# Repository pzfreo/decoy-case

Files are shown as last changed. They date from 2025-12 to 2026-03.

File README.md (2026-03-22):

# decoy-case




A small 3D printed enclosure for a [common USB-C decoy board](https://www.amazon.co.uk/dp/B0FNQNY8PT), built with [build123d](https://github.com/gumyr/build123d).

You can customise how tall the entry is for the wire at the back.

## How it works

1. `decoy_case.py` generates two STEP files (base + shell) using build123d
2. CI builds the STEP files on every push/PR
3. [fabprint](https://github.com/pzfreo/fabprint) slices them with OrcaSlicer in CI, producing print-ready gcode
4. PRs get a comment with estimated print time and filament usage

## Usage

```bash
pip install build123d
python decoy_case.py
```

This generates `decoy_base.step` and `decoy_shell.step`.

To slice locally:

```bash
pip install fabprint
fabprint run
```

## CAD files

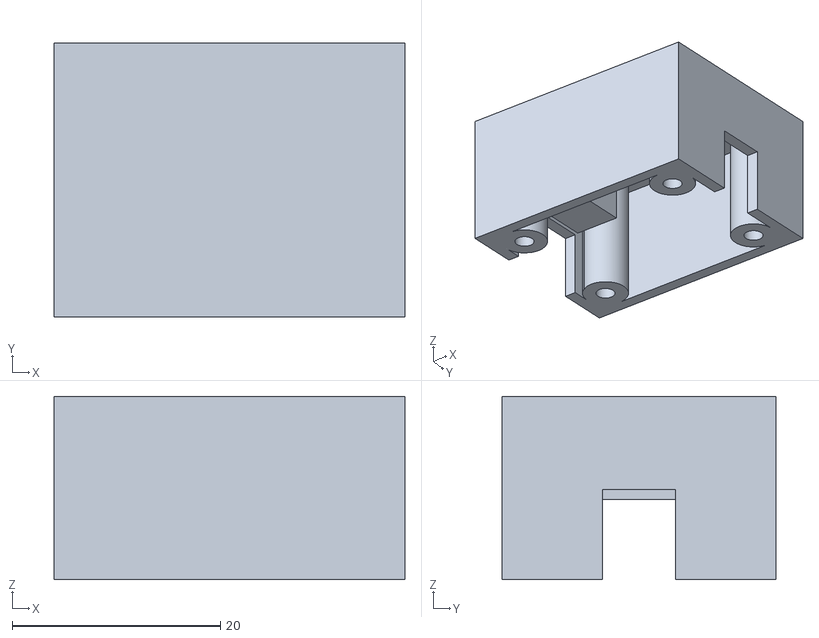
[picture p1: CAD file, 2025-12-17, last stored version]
decoy_shell.stl
33.7 x 26.4 x 17.6

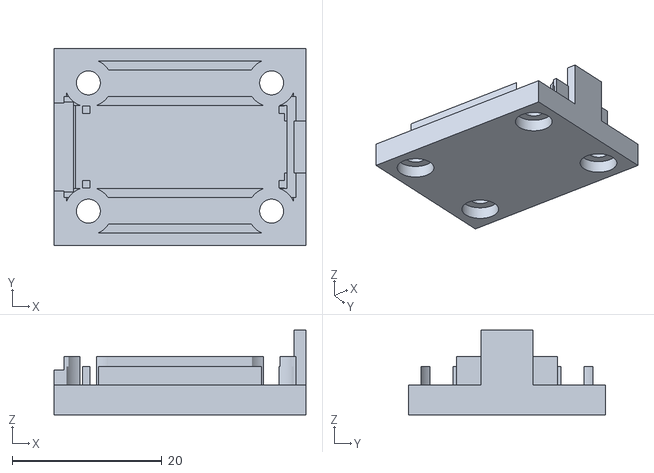
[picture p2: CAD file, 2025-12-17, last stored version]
decoy_base.stl
33.7 x 26.4 x 11.4

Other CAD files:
estampo_output/decoy-case/plate_sliced.gcode.3mf

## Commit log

2025-12-17 first pass
    [decoy_base.stl, decoy_shell.stl]
2026-03-19 Clean up repo: remove binaries, output STEP, add CI
    - Remove committed STL/GLB/BIN files and old/ directory
    - Switch export from STL+GLB to STEP only
    - Add .gitignore entries for generated CAD output
    - Add GitHub Actions workflow to build and verify STEP files
    - Fix markdown link syntax in README
    [decoy_base.stl, decoy_shell.stl]
2026-03-22 Add fabprint CI: slice STEP files on every build
    - Add slice.yml workflow triggered after build.yml via workflow_run
    - Pin slicer profiles into profiles/ for reproducible builds
    - Update README with badges and pipeline description
2026-03-22 Upgrade GitHub Actions to Node.js 24 versions
    - checkout v4 → v6
    - setup-python v5 → v6
    - upload-artifact v4 → v7
    - download-artifact v4 → v8
    - github-script v7 → v8
2026-04-14 Fix print issues on the base and tidy repo (#12)
    Changes to decoy_case.py to make the base print cleanly without supports
    and avoid a tight fit between base and shell:
    - Add 45° self-supporting chamfer above the M3 counterbores so the
    head_dia -> clear_dia step prints without bridging.
    - Bump floor_thick 4.0 -> 5.2 and drop cb_depth 2.0 -> 1.8 to keep
    load-bearing material above the screw heads after the chamfer.
    - Loosen fit_tol 0.20 -> 0.40 for a more forgiving lid/base mate.
    - Shrink the wire-clamp anvil width by fit_tol so it doesn't bind in
    the matching shell notch.
    - Add a 2mm fillet to the outer vertical corners of base and shell.
    - Trim the front PCB-recess wall above the USB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
    [plate_sliced.gcode.3mf]
